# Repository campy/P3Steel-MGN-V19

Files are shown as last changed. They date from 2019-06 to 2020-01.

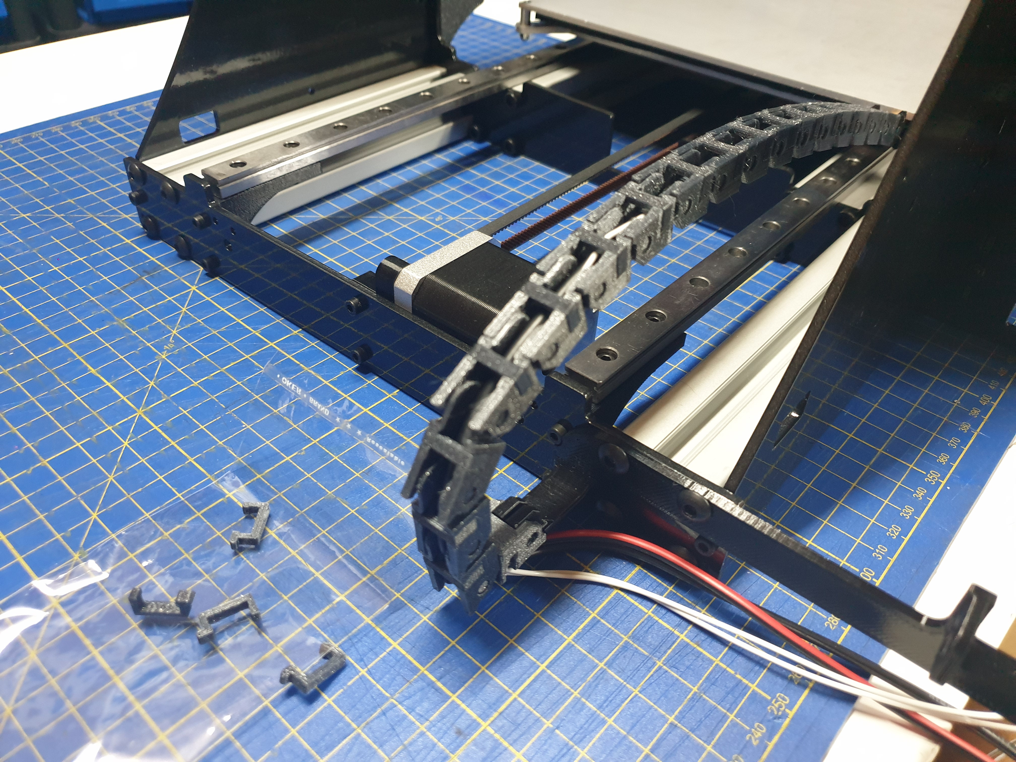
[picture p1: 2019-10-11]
P3Steel MGN Titan/Fotos ensamble/20191008_002519.jpg

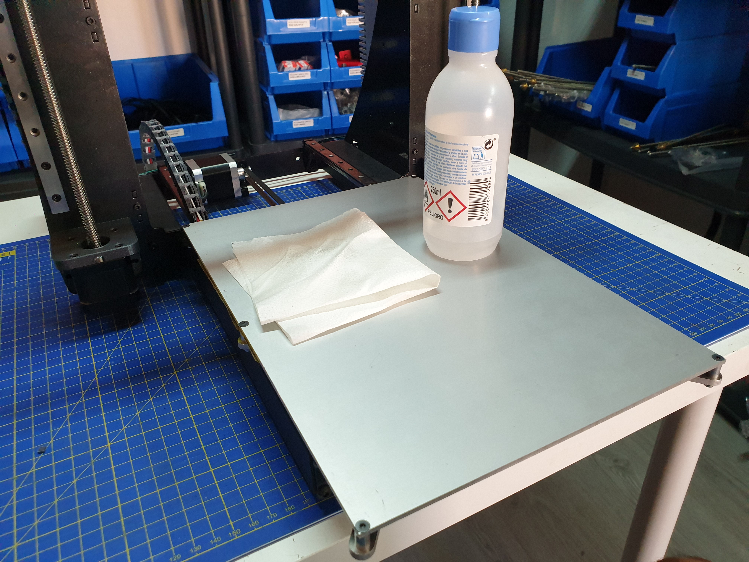
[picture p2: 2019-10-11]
P3Steel MGN Titan/Fotos ensamble/20191009_180815.jpg

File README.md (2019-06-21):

# P3Steel MGN 2019

## Licencia
Proyecto Open-Source con licencia CC BY-NC (No comercial)

Usted puede Compartir — copiar y redistribuir el material en cualquier medio o formato

Usted puede Adaptar — remezclar, transformar y construir a partir del material

NoComercial — Usted no puede hacer uso del material con propósitos comerciales

Atribución — Usted debe dar crédito de manera adecuada, brindar un enlace a la licencia, e indicar si se han realizado cambios. Puede hacerlo en cualquier forma razonable, pero no de forma tal que sugiera que usted o su uso tienen el apoyo de la licenciante.




##  Introducción
Diseñada desde cero por [3DCampy](https://blog.3despana.com/sobre-mi/) y con un año de desarrollo tengo el gusto de presentaros mi proyecto de P3steel

La evolución logica de nuestra querida P3steel, he cuidado hasta el ultimo detalle para que todo encaje a la perfección y la estetica sea lo mas limpia posible

En la wiki podrás ver todos los cambios y mejoras que se van implementando

La nueva P3steel 2019 está diseñada para los usuarios mas exigentes, el movimiento de todos los ejes es por guías lineales, lo que aporta una rigidez estructural y precisión extraordinaria.

Despues del desarrollo y muchas horas de pruebas la P3steel MGN V19 es una plataforma mas que testada y probada, que ademas vamos mejorando día a día con pequeñas mejoras.

Por poco dinero tendrás a tú disposición una impresora de escritorio profesional, robusta y duradera.

## Compatibilidades
- Compatible con extrusor Titan Aero
- Compatible con extrusor Bondtech + E3D V6
- Compatible con electronica MKS Gen L -Marlin 1.1.8-
- Compatible con electronica SKR 1.3 -Marlin 2.0-
- Compatible con electronica Duet 3D
- Compatible con pantalla MKS Mini 12864
- Compatible con pantalla Mini12864 RGB

## Información de cambios y mejoras
[Ir a Wiki](https://wiki.3despana.com/index.php?title=P3Steel_MGN_2019)

## Donde comprar los materiales o impresora completa
[3DEspana.com](https://3despana.com)

## Videos

[Youtube] (https://youtu.be/ORBLZrMCv2k)

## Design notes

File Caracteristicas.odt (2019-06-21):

P3STEEL MGN 2019

Características:

Chasis:

- Estructura de acero de 3mm reforzada con cuatro perfiles de 30x30mm
- Recubrimiento anti-corrosión al polvo en negro metalizado
- Tornilleria DIN 912 pavonada en negro mate

Dimensiones de impresión útiles:

- Eje X – 214mm
- Eje Y – 314mm
- Eje Z – 210mm / 200 (BMG)

Cimematica:

- Cinemática cartesiana mediante guiás lineales de 12mm en todos los ejes
- Patines de re-circulación de bolas en todos los ejes
- Poleas de 16 dientes en XY para mejorar la precisión
- Poleas sincronizadoras dentadas en XY
- Correa de nylon reforzada anti-fricción en XY
- Motores nema 17 con husillo integrado en el eje en el eje Z
- Tuercas Z Pom con muelle y sistema anti-backlash

Motores:

- Motor nema 17 de 1,7ah en eje X
- Motor nema 17 de 2,5ah en eje Y
- Motor nema 17 22mm de bajo peso en el extrusor

Electrónica:

- Placa controladora SKR V1,3 de 32bits
- Cableado de la placa crimpado en conectores JST
- Driver TCM2130 SPI silenciosos controlados por firmware
- Sistema de homing sin finales de carrera
- Driver TMC2208 UART con protector de diodos en el extrusor
- Firmware Marlin 2,0 implementado
- Pantalla RBG 12864 con lector de tarjeta
- Fuente de alimentación 24V 20Ah
- Termistores de temperatura 104-Gt2 de alta precisión en la base y en el nozzle
- Cartucho calefactable de 50w
- Sistema autonivel de 16 puntos mediante un sensor inductivo

Extrusión:

- Boquilla de 0,4mm con acabado electro-pulido
- Filamento de 1,75mm
- Sensor de final de filamento con asistente de cambio de filamento
- Impresión multi-color manual
- Barrel de titanio TC4 anti-goteo
- Funda de silicona protectora en el bloque calefactor
- Extrusión directa guiada para evitar atascos y compatible con filamento flexible
- Extrusor con desmultiplicacion 1/3 de par
- Dos tipos de extrusores a elegir: Titan Aero / BMG

Ventiladores:

- Ventilador de la fuente sustituido por un ventilador de rodamiento dual (Silencioso)
- Ventilador de capa blower de rodamiento dual de 5000rpm
- Ventilador de extrusión de rodamiento dual
- Filtro anti-polvo (Solo en titan)
- Ventilador de electrónica con rodamiento dual silencioso

Base de impresión:

- Superficie de impresión magnética y flexible
- Lamina de impresión de alta adherencia para evitar warping
- Superficies de impresión intercambiables para producción de piezas
- Aislamiento inferior de la superficie para evitar variaciones de temperatura
- Base caliente de aluminio calefactada hasta 120º

Conectividad y Alimentación:

- Conector C14 europeo con interruptor
- Carga de archivos mediante USB o SD
- *Opcional: servidor wifi de gestión de impresiones (Octoprint)

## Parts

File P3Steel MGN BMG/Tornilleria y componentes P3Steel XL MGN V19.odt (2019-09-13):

***********************************

****** GUÍAS LINEALES *******

***********************************

EJE Y

- 2 Guías de 450 mm MGN12C + 4 patines MGN12C

EJE Z y X

- 3 Guías de 500 mm MGN12C + 3 patines MGN12C

***********************************

****** PERFILES 30X30 *******

***********************************

2 Perfiles 30x30 --- 285mm (Zona delantera)

2 Perfiles 30x30 --- 166mm (zona trasera)

***********************************

****** ESTRUCTURA ***********

***********************************

Estructura General

- 12 Tornillos M3x12 (6 por lado)
- 12 tuercas M3 incrustadas en la estructura (6 por cada lado)

Unión de Perfiles con soportes de Metal

- 32 tornillos M5x12

***********************************

****** EJE Y ********************

***********************************

Sujeción Y a las guías 30x30 | (EJ: Pieza 12 a Pieza 22)

- 14 Tornillos M3x10 (7 por guia)
- 14 Tuercas T-Nut (7 por guia)

Sujeción piezas impresa al soporte metal (guías Y) (EJ: Pieza 13 a Pieza 23)

- 4 tornillos M3x10 (2 para cada pieza)
- 4 tuercas T-Nut de perfil 2020 (2 para cada pieza)

Soporte Motor Y a Estructura (EJ: Pieza 16 a Pieza 25)

- 2 Tornillos M3x12
- 2 tuercas m3

Final de carrera Y (EJ: Pieza 15 a Pieza 27)

- 2 Tornillos M3x10
- 2 tuercas M3

Y idler a estructura (soporte Rodamiento Y)

- 3 Tornillos M3x10
- 3 tuercas M3

Polea 3mm a pieza impresa

- 1 Tornillo M3x25
- 1 Tuerca autoblocante M3

Y holder a bandeja (Soporte correa Y)

- 2 Tornillos M3x12
- 2 Tuerca autoblocante M3

Sujeción patines a bandeja

- Cantidad 12 Tornillos M3x8

Motor Y a Soporte

- Cantidad 2 Tornillos M3x10

Soporte cadeneta a base

- Cantidad 1 Tornillo M3x12

Sujeción X a las guías

- 12 Tornillos M3x16

Cama a base aluminio Y

- 5 Tornillos M3x20 Avellanados
- 5 Tuercas autoblocante

***********************************

****** EJE X ********************

***********************************

X-motor - X-idler a Guia Z

- 8 Tornillos M3x8

X-Carriage a Guia de X

- 4 Tornillos M3x8

Sujeccion Guia X a Pieza Impresa X-Motor y X-idler

- 2 Tornillos M3x18 (1 para X-motor y 1 para X-idler)
- 1 Tornillo M3x16 para X-motor (El que coincide con la guia de Z)
- 1 Tornillo M3x14 para X-idler (El que coincide con la guia de Z)
- 4 Tuercas M3

Polea X a X-Idler

- 1 Tornillo M5x30
- 1 Tuerca Autoblocantes

Motor X a Pieza Impresa

- 4 Tornillos M3x10
- 4 Arandelas

***********************************

****** EJE Z ********************

***********************************

Sujeción Guías de Z a estructura de metal

- 12 Tornillos M3 (7 para cada Z)
- 12 Tuercas Autoblocantes (7 para cada Z)

Soporte impreso de motor Z a estructura metal

- 3 Tornillos M3X12
- 6 tuercas M3

Tuerca Husillos de X en pieza impresa

- 6 tornillos M3x12 (3 para cada lado)
- 6 Tuerca autoblocantes (3 para cada lado)

Motores Z a Pieza Impresa Z

- 4 Tornillos M3x8 por cada motor

***********************************

****** CORREAS ***************

***********************************

Correa X 960mm

Correa Y 910mm

***********************************

****** CABLEADO *************

***********************************

600mm Cable de fuente a placa alimentacion

900mm Cable cama a electronica

***********************************

****** ELECTRÓNICA *********

***********************************

Soporte Fuente a Marco + Soporte tapa fuente

4 Tornillos M4x6

Conector C14

2 Tornillos M3x8 Avellanado

2 Tuercas M3

Soporte placa a Marco (electronica + raspy)

4 Tornillos M3x10 Avellanados

Raspy y skr a soporte electrónica

8 Tornillos M3x6

8 insertos (4 por cada placa)

Soporte endstop Y

2 Tornillos M3x10

Soporte bobina filamento

1 Tornillo M3x12 (no entra, aun estando la tuerca incrustada)

1 Tornillo M3x18

1 Tuerca M3

Sensor de filamento a soporte impreso

2 Tornillos M3x18

2 Tuercas M3

Sensor de Filamento a marco de metal superior

1 Tornillo M3x18

Ventilador electrónica a tapa 3x18 avellanado

2 Tornillos M3x18

2 Tuercas M3

LCD RBG

2 Tornillo M3x6

2 Tornillo M3x16

4 insertos

Tapa electrónica

1 Tornillo M3x50

1 Tuerca M3

***********************************

****** INSERTOS **************

***********************************

20 Insertos M3

1 Inserto M6

***********************************

****** TITAN *********

***********************************

1- Anclaje titan no aero a motor 3x10

3- Anclaje aero a motor 3X35 + 4 Arandelas + 1 3x30 corto (Todos con arandela)

2- Ventilador aero 3x16 Avellanados para filtro

2- Ventilador Blower a soporte vent capa 3x20

2- Soporte cadeneta a Vent capa 3x8

Sensor inductivo 24mm desde salida del cable a X carriage

Tubo PTFE Titan 41.60mm (Barrel 4.1)

Tubo PTFE Titan 23.50mm (Barrel TC4)

***********************************

****** BMG *********************

***********************************

Anclaje soporte a guia

- 4 Tornillos M3x8

Anclaje bmg a soporte

- 3 Tornillos M3x36.2 (especiales)

Soporte fan layer a carro central

- 4 Tornillos M3x12
- 4 arandelas

Soporte cadeneta a x carro

- 4 Tornillos M3x6
- 2 Insertos En carro central

Ventilador blower a soporte impreso

- 2 Tornillos M3x20
- Usadas tuercas M3 acero. No hay tuerca de Nylon en el pack

***********************************

****** CADENETAS ************

***********************************

EJE Y (cama)

- 20x Eslabon 5

EJE Z

- 23x Eslabones
- 21 tapas R
- 2 tapas finas

CASO BMG (EJE X)

- 23 Eslabones + Eslabon Bloqueado
- 21 tapas L
- 1 tapa fina

CASO TITAN (EJE X)

- 18 Eslabones 15 (Eje X)
- 16 Tapas L
- 2 Tapa fina

TORNILLOS CADENETAS
Xmotor a Soporte de Cadeneta

- 4 Tornillos M3X6
- 4 insertos

X-Carriage a Soporte de Cadeneta

- 2 tornillos M3x8

***********************************

****** CABLES

***********************************

Estos son los alargamientos necesarios de cables:

EJE X a Electrónica

- 1 metro extra cable 2 nucleos 24 awg calentador Hotend.
- 1 metro extra cable 2 nucleos 28 awg Termistor Hotend.
- 1 metro extra cable 3 nucleos 28 awg inductor.
- 1 metro extra cable 2 nucleos 28 awg para Ventilador capa
- 1 metro extra cable 2 nucleos 28 awg para ventilador Extrusor
- 1,5 metro extra cable para Final de carrera de X

Fuente a Electrónica:

- 1,4 metros cable 2.5mm de Fuente a Electrónica (Cable Positivo, Negativo y Tierra)
- 1,4 metros cable 4mm de Fuente a Mofset (cable Positivo y Negativo)

Cama a Electrónica:

- 1 Metro cable 4mm de Mofset a cama (cable Positivo y Negativo)
- 1 Metro cable 28 AWG Termistor a Electrónica (Positivo y Negativo)

Enchufe CP12:

- 3 cables de 4 cm 2.5mm para puentes
- 3 cables de 8 cm de 2.5mm hasta fuente de alimentacion

***********************************

****** VREF DRIVERS ********

***********************************

TMC 2208

- X - 750mv
- Y - 800mv (0.9ยบ - 1300mv)
- Z - 800mv
- E - 750mv

TMC 2209

- X - ???mv
- Y - ???mv
- Z - ???mv
- E - ???mv

TMC 2130

- X - ???mv
- Y - ???mv
- Z - ???mv
- E - ???mv

***********************************

****** SENSOR INDUCTIVO **

***********************************

5V - MARRON

GND - AZUL

1.25 - NEGRO

***********************************

****** SENSOR FILAMENTO**

***********************************

Pin 1.28 (X+)

Pin GND

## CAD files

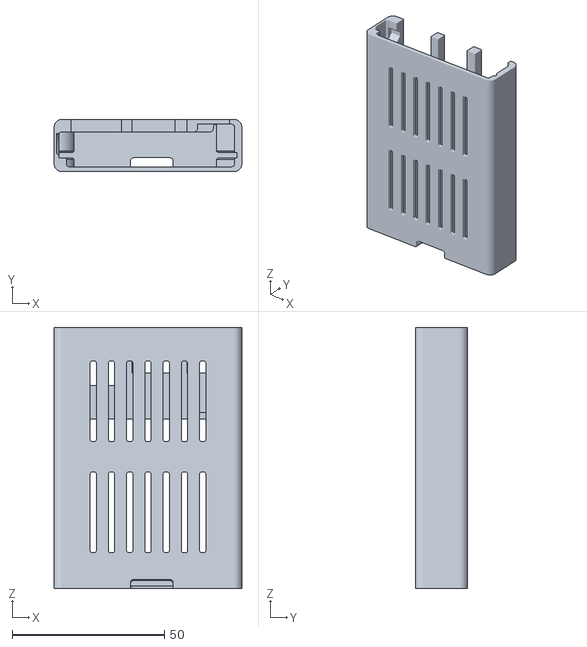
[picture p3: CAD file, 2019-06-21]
P3Steel MGN BMG/Piezas impresas/Raspberry box/Raspberry_Pi_B+_Sleeve_v2-1_MAIN.STL
61.7 x 17.2 x 85.8

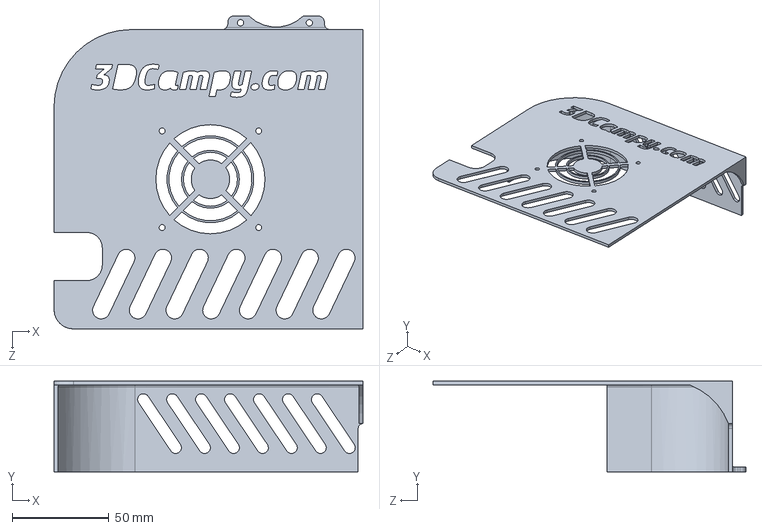
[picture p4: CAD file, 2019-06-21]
P3Steel MGN BMG/Piezas impresas/Soportes electronicas/Tapa Electronica antigua/Tapa Total.SLDPRT
160.0 x 47.0 x 162.0 mm

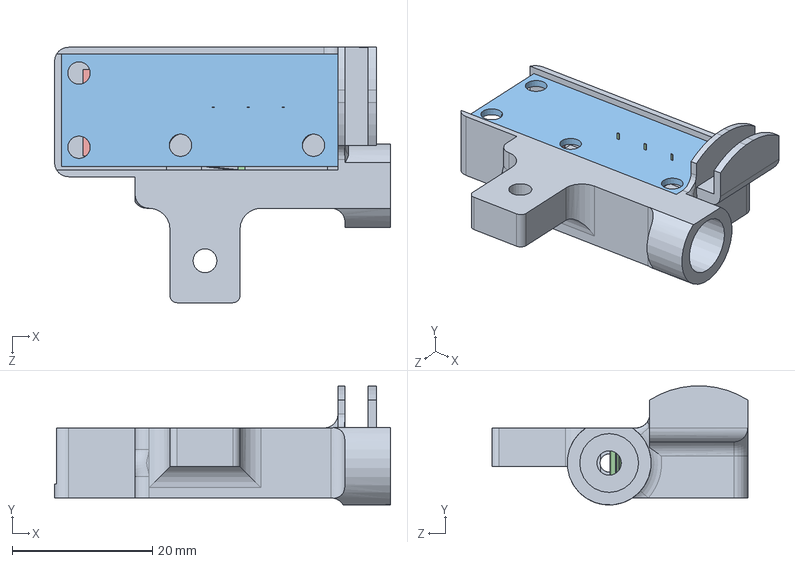
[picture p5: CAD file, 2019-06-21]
P3Steel MGN BMG/Source/F-Sensor/Ensamblaje F-Sensor.SLDASM
48.0 x 17.0 x 36.5 mm
Soporte F-Sensor
Konstruktion24
PCB^Endstop
Microswitch_1A_125vAC(seul)
JST 4Pin

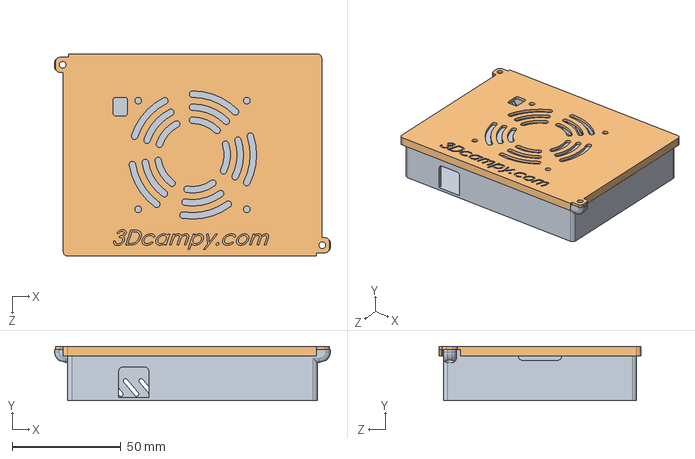
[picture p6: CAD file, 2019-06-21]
P3Steel MGN Titan/Piezas impresas/Soportes electronicas/Caja MKS SKR/EnsamblajeCajaMKS.SLDASM
127.0 x 25.0 x 93.0 mm
CajaMKSGen
TapaMKSGen

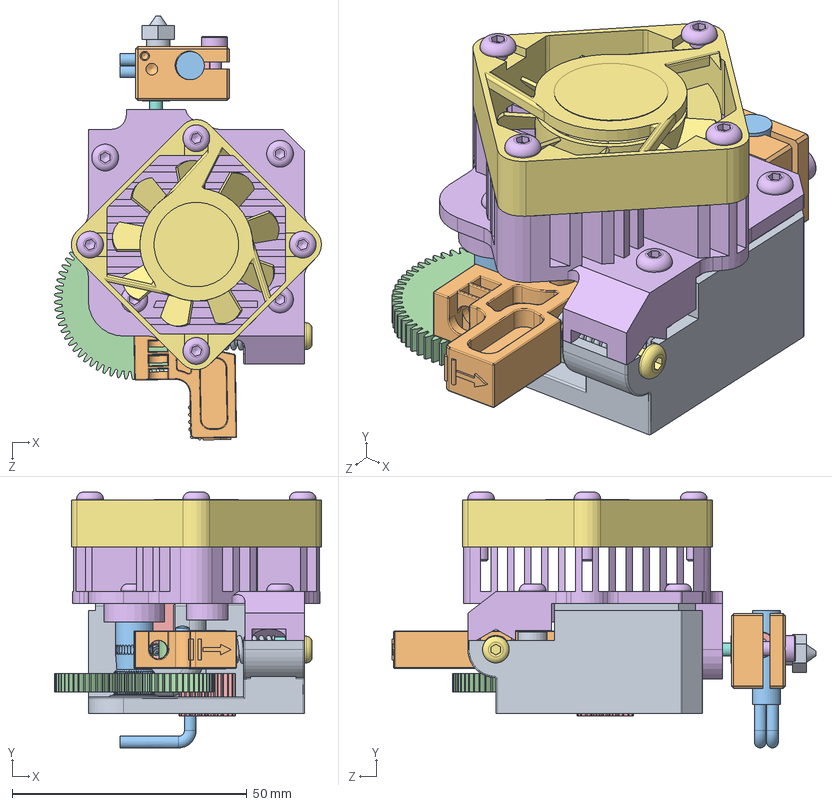
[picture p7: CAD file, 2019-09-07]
P3Steel MGN Titan/Source/Titan Aero/Titan Aero P3steel/e3d titan areo 1.751.SLDASM
56.8 x 54.4 x 90.2 mm
Base
9x5x3mm bearing x 2
hobbed wheel
filament gear
motor gear
cover
m3x8
M3 nut
idler spring
tensioner
idler bearing pin
idler bearing
guide tube
ISO 7380 - M3 x 28 v1 x 8
Fan 40 X 40 X 10 v4
E3D v6 HotEnd - Heatbreak
E3D v6 HotEnd - Nozzle
E3D v6 HotEnd - Heat Block
Ceramic Cartridge Heater
Thermistor
HEXAGON SOCKET HEAD CAP SCREWS_SCB3-4
HEXAGON SOCKET HEAD CAP SCREWS_SCB3-10
Flat Washers_PWF3

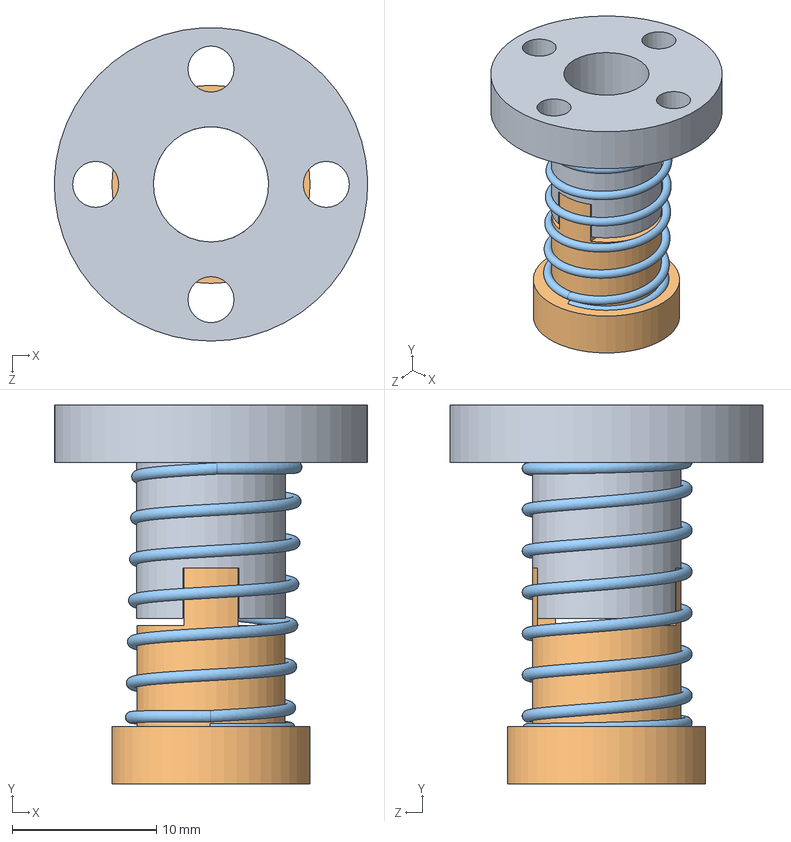
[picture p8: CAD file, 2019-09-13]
P3Steel MGN BMG/Ensamblaje-Xidler.SLDASM
21.7 x 26.3 x 21.7 mm
nakretka tr08
napinacz nakretki tr8
sprezyna nakretka tr 8

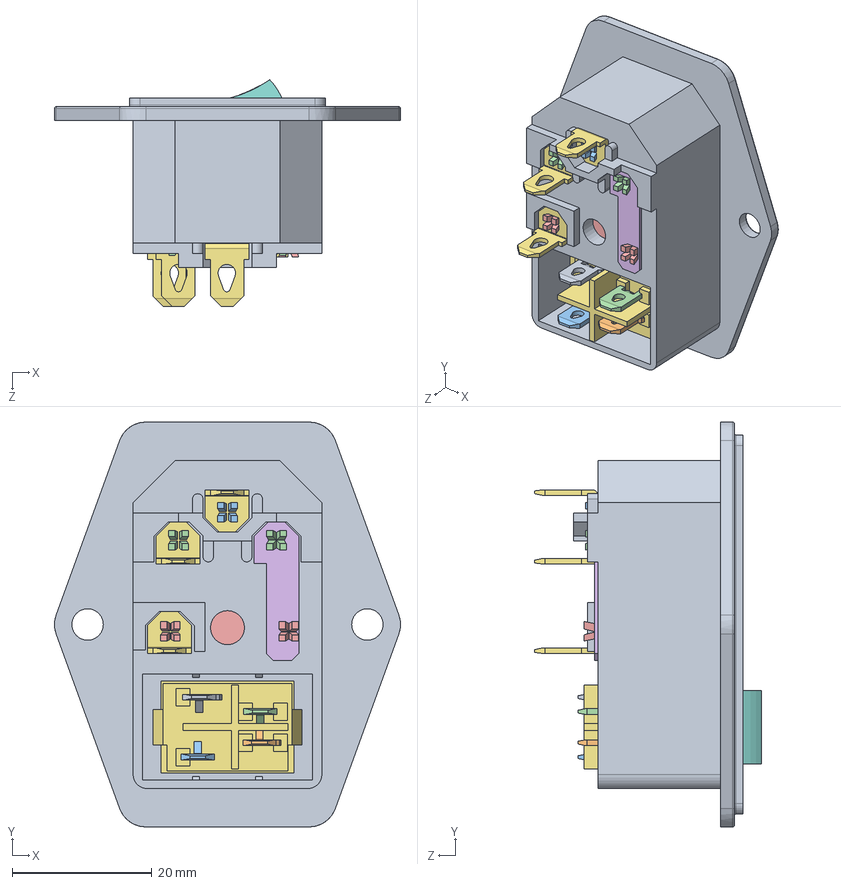
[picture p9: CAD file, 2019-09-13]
P3Steel MGN BMG/Source/Conector C14/IEC320-C14.SLDASM
49.5 x 57.9 x 32.4 mm
ilpm_case
fuse_clip_set
blade_15
blade_12 x 2
fuse-holder
fuse
switch_base
rocker
sm_tab_type1a
sm_tab_type1b
sm_tab_type2a
sm_tab_type2b
spot x 2
stamped_cond
correct_big_tab x 3

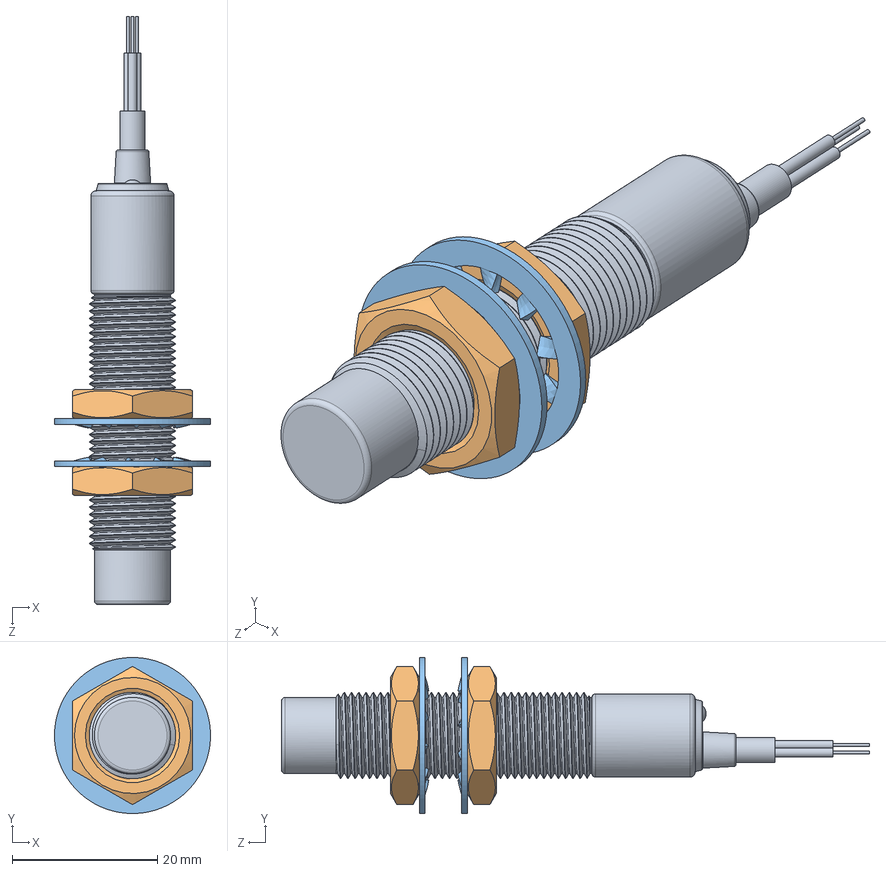
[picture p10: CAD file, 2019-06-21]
P3Steel MGN BMG/Source/Inductive Sensor/LJ12A3-4-Z.SLDASM
21.5 x 21.5 x 81.0 mm
LJ12A3-4-Z
Гайка М12 x 2
Шайба x 2

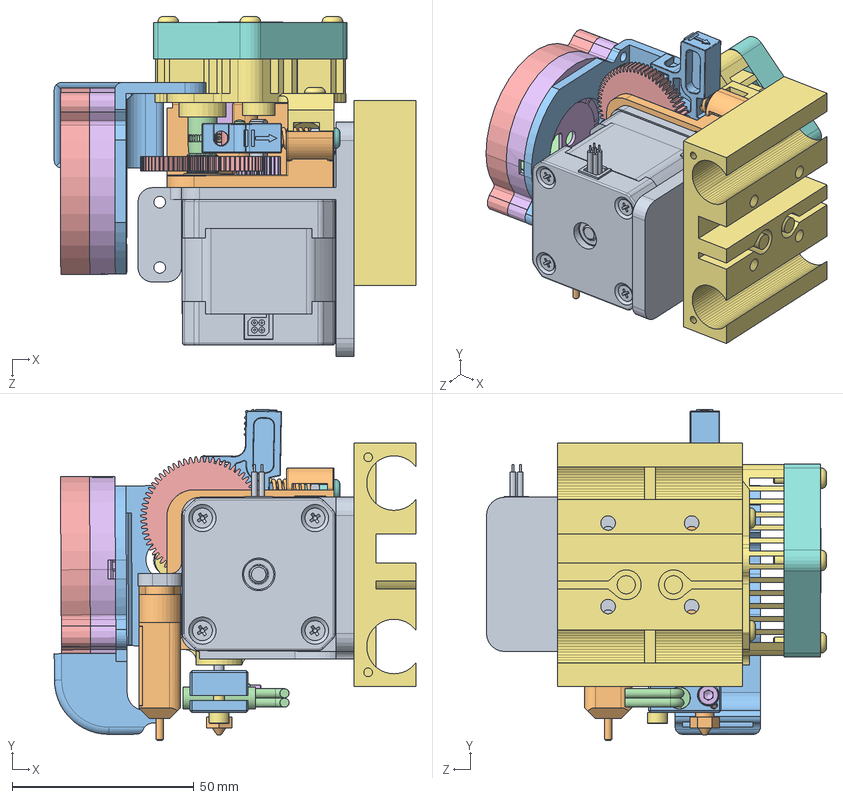
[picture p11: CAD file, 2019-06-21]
P3Steel MGN BMG/Source/Titan Aero/Titan Aero P3steel/soportetitan.SLDASM
99.6 x 91.2 x 93.6 mm
soportetitan
Base
9x5x3mm bearing x 2
hobbed wheel
filament gear
motor gear
cover
m3x8
M3 nut
idler spring
tensioner
idler bearing pin
idler bearing
guide tube
ISO 7380 - M3 x 28 v1 x 8
Fan 40 X 40 X 10 v4
E3D v6 HotEnd - Heatbreak
E3D v6 HotEnd - Nozzle
E3D v6 HotEnd - Heat Block
Ceramic Cartridge Heater
Thermistor
HEXAGON SOCKET HEAD CAP SCREWS_SCB3-4
HEXAGON SOCKET HEAD CAP SCREWS_SCB3-10
Flat Washers_PWF3
17HM15-0904S
BLTouch
tobera5015s
turbine
top
bottom
xcarriage

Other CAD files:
P3Steel MGN BMG/Piezas impresas/Soportes electronicas/Placas/Duet Wifi/2X5Pin case v6_1.sldasm
P3Steel MGN BMG/Source/Endstop/Component2.sldasm
P3Steel MGN Titan/Piezas impresas/Soportes electronicas/Placas/Duet Wifi/2X25Pin case v7.sldasm
P3Steel MGN Titan/Source/Endstop/Component3.sldasm
P3Steel MGN BMG/Source/F-Sensor/PCB.sldasm
P3Steel MGN Titan/Ensamblaje-Xidler.SLDASM
P3Steel MGN BMG/Bandeja 300.SLDPRT
P3Steel MGN BMG/Ensamblaje-Xmotor.SLDASM
P3Steel MGN BMG/Escuadra Central.SLDPRT
P3Steel MGN BMG/Escuadra Superior.SLDPRT
P3Steel MGN BMG/Extrusor/X-CarriageV2 BMG.SLDPRT
P3Steel MGN BMG/Extrusor/X-CarriageV2 BMG.STL
P3Steel MGN BMG/Frente.SLDPRT
P3Steel MGN BMG/Marco central.SLDPRT
P3Steel MGN BMG/Piezas impresas/Alzador.SLDPRT
P3Steel MGN BMG/Piezas impresas/Alzador.STL
P3Steel MGN BMG/Piezas impresas/Cadenetas/Cadeneta 15/Cierre 15 Tapa L.SLDPRT
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

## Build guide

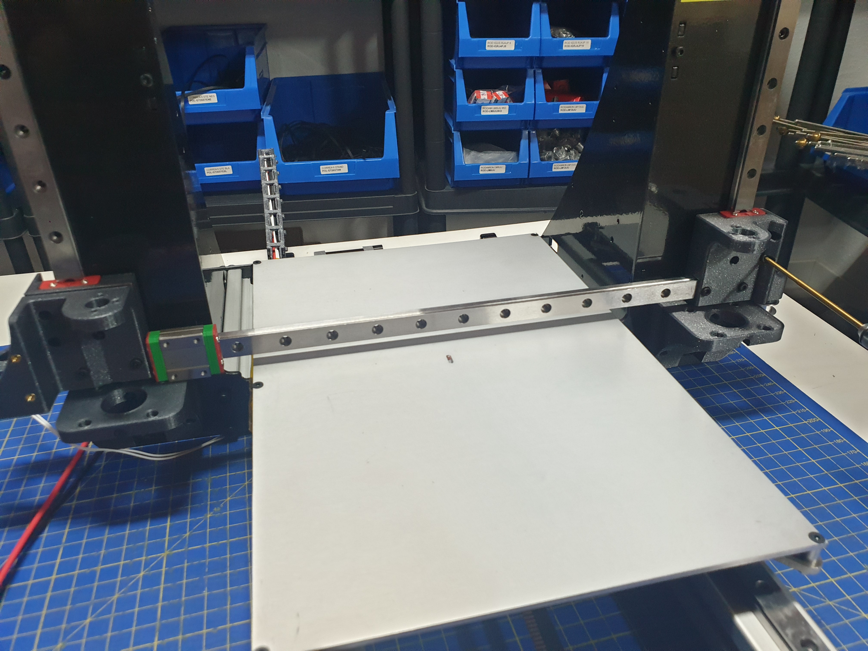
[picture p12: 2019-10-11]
P3Steel MGN Titan/Fotos ensamble/20191008_003525.jpg

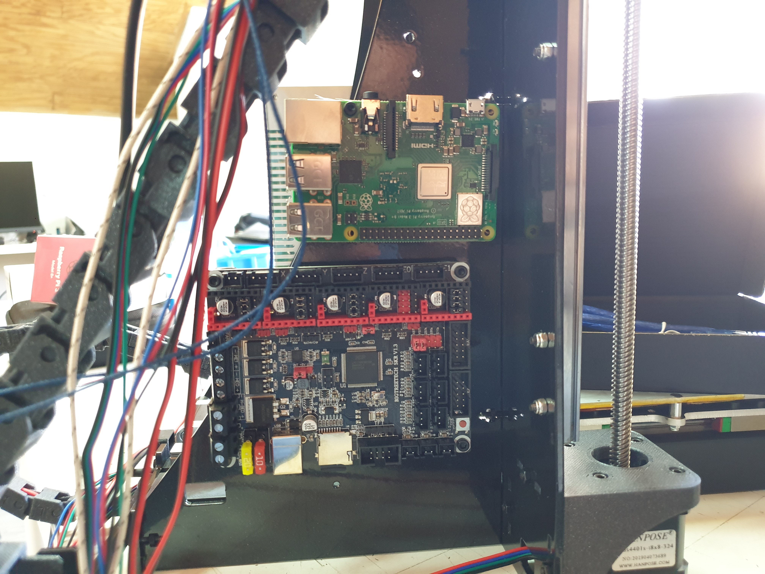
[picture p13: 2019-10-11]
P3Steel MGN Titan/Fotos ensamble/20191009_143709.jpg

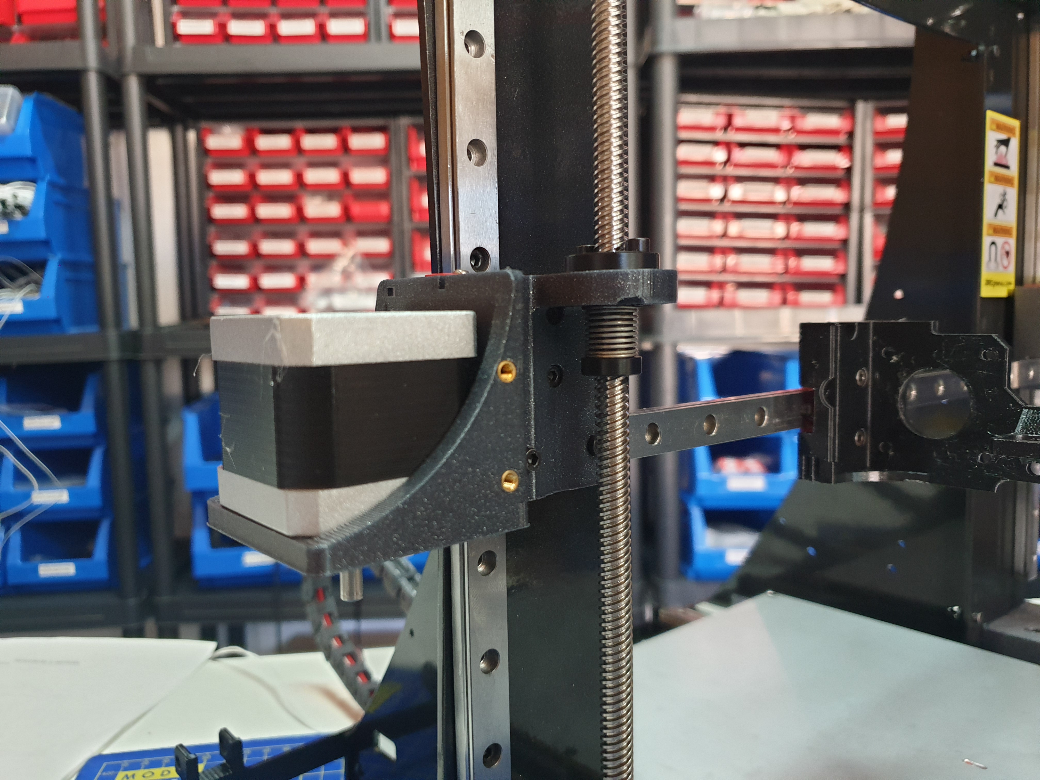
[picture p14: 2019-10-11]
P3Steel MGN Titan/Fotos ensamble/20191008_133851.jpg

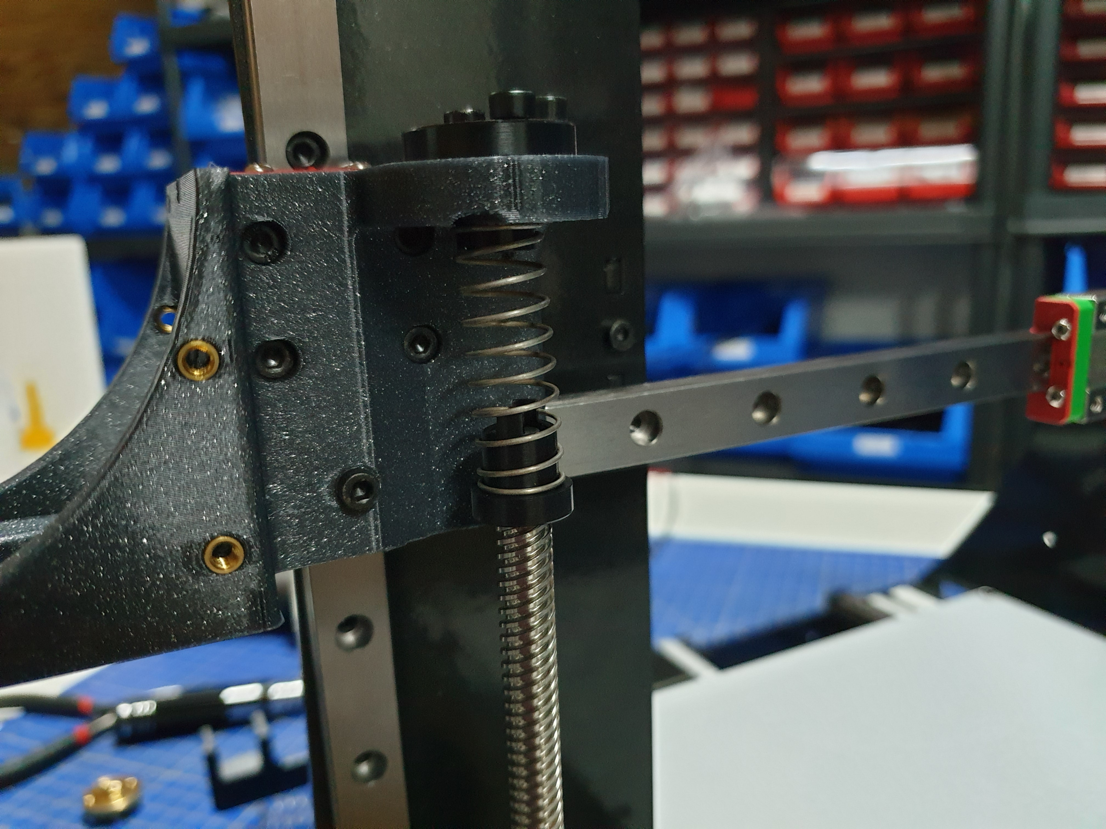
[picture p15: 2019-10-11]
P3Steel MGN Titan/Fotos ensamble/20191008_005819.jpg

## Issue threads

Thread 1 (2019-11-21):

Marlin 1.1.9

kikirikiki, 2019-11-21:
Hola,
he visto tu canal de youtube donde explicas la configuración de Marlin 1.1.9 entre otras cosas. Me ha encantado, muchas gracias.

He ido siguiendo tus indicaciones y llego a un punto donde no puedo continuar. Al acabar la configuracion, tengo un problema y es que no me compila el programa. He tenido que cambiar algo que no se lo que es y la he liado. Igual tu me puedes echar una mano, porque la verdad que no se por donde tirar.
Este es el error:
#error "DISABLE_[XYZ] is not compatible with HOME_AFTER_DEACTIVATE or Z_SAFE_HOMING."

Muchas gracias!!
Un saludo!

Joseba1478, 2020-04-15:
Hola Buenos días.
Soy nuevo por aquí y quisiera hacerme una impresora 3D y la verdad que la esteel v19 me encanta y quisiera hacerme una.
Quisiera saber como poder bajarme los planos de láser DXF.
Muchas gracias x todo.
Saludos.

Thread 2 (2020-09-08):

Motors not working in ramp 1.6 marlin 1.1.x

ammarfarsi, 2020-09-08:
hello.
I use marlin 1.1.9 on ramps 1.6 but the problem the motors not working. I check the connection but it is correct. also, I use Vref for a driver I try 0.3, 0.42, 0.52, 0.72 , 0.93V but still motors not working. I use pronterface to check the printer is connected but motors not move. i work with A4988 driver
[Marlin-bugfix-1.1.xmmm.zip](https://github.com/campy/P3Steel-MGN-V19/files/5189359/Marlin-bugfix-1.1.xmmm.zip)

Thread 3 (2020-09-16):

include errors detected, update include path

ammarfarsi, 2020-09-16:
i have this problem in vs code can any help me ?
#include errors detected. Please update your includePath. Squiggles are disabled for this translation unit (C:\Users\user\Desktop\Marlin-2.0.x\Marlin\src\MarlinCore.cpp).

abdallahelhady, 2023-06-25:
Is it solved with you?

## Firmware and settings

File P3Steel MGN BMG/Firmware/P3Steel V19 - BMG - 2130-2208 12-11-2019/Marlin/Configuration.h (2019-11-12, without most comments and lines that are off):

#pragma once
#define CONFIGURATION_H_VERSION 020000
#define STRING_CONFIG_H_AUTHOR "(none, default config)" // Who made the changes.
#define SHOW_BOOTSCREEN
#define SERIAL_PORT -1
#define BAUDRATE 115200
  #define MOTHERBOARD BOARD_BIGTREE_SKR_V1_3
#define CUSTOM_MACHINE_NAME "P3Steel V19"
#define EXTRUDERS 1
#define DEFAULT_NOMINAL_FILAMENT_DIA 1.75
#define TEMP_SENSOR_0 5
#define TEMP_SENSOR_1 0
#define TEMP_SENSOR_2 0
#define TEMP_SENSOR_3 0
#define TEMP_SENSOR_4 0
#define TEMP_SENSOR_5 0
#define TEMP_SENSOR_BED 11
#define TEMP_SENSOR_CHAMBER 0
#define DUMMY_THERMISTOR_998_VALUE 25
#define DUMMY_THERMISTOR_999_VALUE 100
#define MAX_REDUNDANT_TEMP_SENSOR_DIFF 10
#define TEMP_RESIDENCY_TIME     10  // (seconds) Time to wait for hotend to "settle" in M109
#define TEMP_WINDOW              1  // (°C) Temperature proximity for the "temperature reached" timer
#define TEMP_HYSTERESIS          3  // (°C) Temperature proximity considered "close enough" to the target
#define TEMP_BED_RESIDENCY_TIME 10  // (seconds) Time to wait for bed to "settle" in M190
#define TEMP_BED_WINDOW          1  // (°C) Temperature proximity for the "temperature reached" timer
#define TEMP_BED_HYSTERESIS      3  // (°C) Temperature proximity considered "close enough" to the target
#define HEATER_0_MINTEMP   5
#define HEATER_1_MINTEMP   5
#define HEATER_2_MINTEMP   5
#define HEATER_3_MINTEMP   5
#define HEATER_4_MINTEMP   5
#define HEATER_5_MINTEMP   5
#define BED_MINTEMP        5
#define HEATER_0_MAXTEMP 275
#define HEATER_1_MAXTEMP 275
#define HEATER_2_MAXTEMP 275
#define HEATER_3_MAXTEMP 275
#define HEATER_4_MAXTEMP 275
#define HEATER_5_MAXTEMP 275
#define BED_MAXTEMP      150
#define PIDTEMP
#define BANG_MAX 255     // Limits current to nozzle while in bang-bang mode; 255=full current
#define PID_MAX BANG_MAX // Limits current to nozzle while PID is active (see PID_FUNCTIONAL_RANGE below); 255=full current
#define PID_K1 0.95      // Smoothing factor within any PID loop
  #define PID_EDIT_MENU         // Add PID editing to the "Advanced Settings" menu. (~700 bytes of PROGMEM)
  #define PID_AUTOTUNE_MENU     // Add PID auto-tuning to the "Advanced Settings" menu. (~250 bytes of PROGMEM)
  #define PID_FUNCTIONAL_RANGE 10 // If the temperature difference between the target temperature and the actual temperature
  #define DEFAULT_Kp 11.0
  #define DEFAULT_Ki 0.62
  #define DEFAULT_Kd 48.67
#define PIDTEMPBED
#define MAX_BED_POWER 255 // limits duty cycle to bed; 255=full current
  #define DEFAULT_bedKp 794.49
  #define DEFAULT_bedKi 93.60
  #define DEFAULT_bedKd 1686.01
#define PREVENT_COLD_EXTRUSION
#define EXTRUDE_MINTEMP 170
#define PREVENT_LENGTHY_EXTRUDE
#define EXTRUDE_MAXLENGTH 200
#define THERMAL_PROTECTION_HOTENDS // Enable thermal protection for all extruders
#define THERMAL_PROTECTION_BED     // Enable thermal protection for the heated bed
#define THERMAL_PROTECTION_CHAMBER // Enable thermal protection for the heated chamber
#define USE_XMIN_PLUG
#define USE_YMIN_PLUG
#define USE_ZMIN_PLUG
#define ENDSTOPPULLUPS
#define X_MIN_ENDSTOP_INVERTING true // Set to true to invert the logic of the endstop.
#define Y_MIN_ENDSTOP_INVERTING true // Set to true to invert the logic of the endstop.
#define Z_MIN_ENDSTOP_INVERTING true // Set to true to invert the logic of the endstop.
#define X_MAX_ENDSTOP_INVERTING false // Set to true to invert the logic of the endstop.
#define Y_MAX_ENDSTOP_INVERTING false // Set to true to invert the logic of the endstop.
#define Z_MAX_ENDSTOP_INVERTING false // Set to true to invert the logic of the endstop.
#define Z_MIN_PROBE_ENDSTOP_INVERTING true // Set to true to invert the logic of the probe.
#define X_DRIVER_TYPE  TMC2130
#define Y_DRIVER_TYPE  TMC2130
#define Z_DRIVER_TYPE  TMC2130
#define E0_DRIVER_TYPE TMC2208
#define DEFAULT_AXIS_STEPS_PER_UNIT   { 100, 100, 400, 415 }
#define DEFAULT_MAX_FEEDRATE          { 100, 100, 8, 40 }
#define DEFAULT_MAX_ACCELERATION      { 1500, 1500, 500, 10000 }
#define DEFAULT_ACCELERATION          1500    // X, Y, Z and E acceleration for printing moves
#define DEFAULT_RETRACT_ACCELERATION  1500    // E acceleration for retracts
#define DEFAULT_TRAVEL_ACCELERATION   1500    // X, Y, Z acceleration for travel (non printing) moves
#define DEFAULT_EJERK    5.0  // May be used by Linear Advance
  #define JUNCTION_DEVIATION_MM 0.010 // (mm) Distance from real junction edge
#define Z_MIN_PROBE_USES_Z_MIN_ENDSTOP_PIN
#define Z_MIN_PROBE_PIN 25 // Pin 32 is the RAMPS default
#define FIX_MOUNTED_PROBE
#define NOZZLE_TO_PROBE_OFFSET { 0, -27, -3.0 }
#define MIN_PROBE_EDGE 10
#define XY_PROBE_SPEED 7000
#define Z_PROBE_SPEED_FAST HOMING_FEEDRATE_Z
#define Z_PROBE_SPEED_SLOW (Z_PROBE_SPEED_FAST / 2)
#define Z_CLEARANCE_DEPLOY_PROBE    5 // Z Clearance for Deploy/Stow
#define Z_CLEARANCE_BETWEEN_PROBES  5 // Z Clearance between probe points
#define Z_CLEARANCE_MULTI_PROBE     5 // Z Clearance between multiple probes
#define Z_AFTER_PROBING           5 // Z position after probing is done
#define Z_PROBE_LOW_POINT          -2 // Farthest distance below the trigger-point to go before stopping
#define Z_PROBE_OFFSET_RANGE_MIN -20
#define Z_PROBE_OFFSET_RANGE_MAX 20
#define X_ENABLE_ON 0
#define Y_ENABLE_ON 0
#define Z_ENABLE_ON 0
#define E_ENABLE_ON 0 // For all extruders
#define DISABLE_X false
#define DISABLE_Y false
#define DISABLE_Z false
#define DISABLE_E false             // For all extruders
#define DISABLE_INACTIVE_EXTRUDER   // Keep only the active extruder enabled
#define INVERT_X_DIR false
#define INVERT_Y_DIR true
#define INVERT_Z_DIR false
#define INVERT_E0_DIR false
#define INVERT_E1_DIR false
#define INVERT_E2_DIR false
#define INVERT_E3_DIR false
#define INVERT_E4_DIR false
#define INVERT_E5_DIR false
#define X_HOME_DIR -1
#define Y_HOME_DIR -1
#define Z_HOME_DIR -1
#define X_BED_SIZE 212
#define Y_BED_SIZE 310
#define X_MIN_POS 0
#define Y_MIN_POS 0
#define Z_MIN_POS 0
#define X_MAX_POS X_BED_SIZE
#define Y_MAX_POS Y_BED_SIZE
#define Z_MAX_POS 220
#define MIN_SOFTWARE_ENDSTOPS
  #define MIN_SOFTWARE_ENDSTOP_X
  #define MIN_SOFTWARE_ENDSTOP_Y
  #define MIN_SOFTWARE_ENDSTOP_Z
#define MAX_SOFTWARE_ENDSTOPS
  #define MAX_SOFTWARE_ENDSTOP_X
  #define MAX_SOFTWARE_ENDSTOP_Y
  #define MAX_SOFTWARE_ENDSTOP_Z
#define FILAMENT_RUNOUT_SENSOR
  #define NUM_RUNOUT_SENSORS   1     // Number of sensors, up to one per extruder. Define a FIL_RUNOUT#_PIN for each.
  #define FIL_RUNOUT_INVERTING true // Set to true to invert the logic of the sensor.
  #define FIL_RUNOUT_PULLUP          // Use internal pullup for filament runout pins.
  #define FILAMENT_RUNOUT_SCRIPT "M600"
#define AUTO_BED_LEVELING_BILINEAR
  #define ENABLE_LEVELING_FADE_HEIGHT
  #define SEGMENT_LEVELED_MOVES
  #define LEVELED_SEGMENT_LENGTH 5.0 // (mm) Length of all segments (except the last one)
  #define GRID_MAX_POINTS_X 4
  #define GRID_MAX_POINTS_Y GRID_MAX_POINTS_X
#define Z_SAFE_HOMING
  #define Z_SAFE_HOMING_X_POINT ((X_BED_SIZE) / 2)    // X point for Z homing when homing all axes (G28).
  #define Z_SAFE_HOMING_Y_POINT ((Y_BED_SIZE) / 2)    // Y point for Z homing when homing all axes (G28).
#define HOMING_FEEDRATE_XY (90*60)
#define HOMING_FEEDRATE_Z  (8*60)
#define VALIDATE_HOMING_ENDSTOPS
#define EEPROM_SETTINGS     // Persistent storage with M500 and M501
#define EEPROM_CHITCHAT       // Give feedback on EEPROM commands. Disable to save PROGMEM.
#define HOST_KEEPALIVE_FEATURE        // Disable this if your host doesn't like keepalive messages
#define DEFAULT_KEEPALIVE_INTERVAL 2  // Number of seconds between "busy" messages. Set with M113.
#define BUSY_WHILE_HEATING            // Some hosts require "busy" messages even during heating
#define PREHEAT_1_LABEL       "PLA"
#define PREHEAT_1_TEMP_HOTEND 205
#define PREHEAT_1_TEMP_BED     50
#define PREHEAT_1_FAN_SPEED     0 // Value from 0 to 255
#define PREHEAT_2_LABEL       "ABS"
#define PREHEAT_2_TEMP_HOTEND 220
#define PREHEAT_2_TEMP_BED     90
#define PREHEAT_2_FAN_SPEED     0 // Value from 0 to 255
#define NOZZLE_PARK_FEATURE
  #define NOZZLE_PARK_POINT { (X_MIN_POS + 10), (Y_MAX_POS - 10), 20 }
  #define NOZZLE_PARK_XY_FEEDRATE 100   // (mm/s) X and Y axes feedrate (also used for delta Z axis)
  #define NOZZLE_PARK_Z_FEEDRATE 5      // (mm/s) Z axis feedrate (not used for delta printers)
#define PRINTJOB_TIMER_AUTOSTART
#define PRINTCOUNTER
#define LCD_LANGUAGE es
#define DISPLAY_CHARSET_HD44780 JAPANESE
#define LCD_INFO_SCREEN_STYLE 0
#define SDSUPPORT
#define FYSETC_MINI_12864_1_2  // Type C/D/E/F. Simple RGB Backlight (always on)
#define SOFT_PWM_SCALE 0
#define SERVO_DELAY { 300 }

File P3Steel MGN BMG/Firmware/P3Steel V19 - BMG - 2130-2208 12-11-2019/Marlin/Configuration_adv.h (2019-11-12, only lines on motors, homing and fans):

#define E0_AUTO_FAN_PIN -1
#define E1_AUTO_FAN_PIN -1
#define E2_AUTO_FAN_PIN -1
#define E3_AUTO_FAN_PIN -1
#define E4_AUTO_FAN_PIN -1
#define E5_AUTO_FAN_PIN -1
#define CHAMBER_AUTO_FAN_PIN -1
#define X_HOME_BUMP_MM 0
#define Y_HOME_BUMP_MM 0
#define Z_HOME_BUMP_MM 2
#define HOMING_BUMP_DIVISOR { 2, 2, 4 }  // Re-Bump Speed Divisor (Divides the Homing Feedrate)
#define MICROSTEP_MODES { 16, 16, 16, 16, 16, 16 } // [1,2,4,8,16]
#define DIGIPOT_I2C_MOTOR_CURRENTS { 1.0, 1.0, 1.0, 1.0, 1.0, 1.0, 1.0, 1.0 }  //  AZTEEG_X3_PRO
#define LIN_ADVANCE
  #define LIN_ADVANCE_K 0.20    // Unit: mm compression per 1mm/s extruder speed
#define ADVANCED_PAUSE_FEATURE
  #define ADVANCED_PAUSE_PURGE_FEEDRATE        3  // (mm/s) Extrude feedrate (after loading). Should be slower than load feedrate.
  #define ADVANCED_PAUSE_PURGE_LENGTH         70  // (mm) Length to extrude after loading.
  #define ADVANCED_PAUSE_RESUME_PRIME          0  // (mm) Extra distance to prime nozzle after returning from park.
    #define X_CURRENT       750       // (mA) RMS current. Multiply by 1.414 for peak current.
    #define X_CURRENT_HOME  X_CURRENT  // (mA) RMS current for sensorless homing
    #define X_MICROSTEPS     16    // 0..256
    #define Y_CURRENT       925
    #define Y_CURRENT_HOME  Y_CURRENT
    #define Y_MICROSTEPS     16
    #define Z_CURRENT       800
    #define Z_CURRENT_HOME  Z_CURRENT
    #define Z_MICROSTEPS     16
    #define E0_CURRENT      720
    #define E0_MICROSTEPS    16
    #define CURRENT_STEP_DOWN     50  // [mA]
    #define REPORT_CURRENT_CHANGE
  #define X_HYBRID_THRESHOLD     100  // [mm/s]
  #define X2_HYBRID_THRESHOLD    100
  #define Y_HYBRID_THRESHOLD     100
  #define Y2_HYBRID_THRESHOLD    100
  #define Z_HYBRID_THRESHOLD       3
  #define Z2_HYBRID_THRESHOLD      3
  #define Z3_HYBRID_THRESHOLD      3
  #define E0_HYBRID_THRESHOLD     30
  #define E1_HYBRID_THRESHOLD     30
  #define E2_HYBRID_THRESHOLD     30
  #define E3_HYBRID_THRESHOLD     30
  #define E4_HYBRID_THRESHOLD     30
  #define E5_HYBRID_THRESHOLD     30
  #define SENSORLESS_HOMING // StallGuard capable drivers only
    #define X_STALL_SENSITIVITY  5
    #define X2_STALL_SENSITIVITY X_STALL_SENSITIVITY
    #define Y_STALL_SENSITIVITY  5

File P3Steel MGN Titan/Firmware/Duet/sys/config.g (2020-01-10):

; Configuration file for Duet WiFi (firmware version 1.21)
; executed by the firmware on start-up
;
; generated by RepRapFirmware Configuration Tool on Tue Oct 23 2018 00:51:50 GMT+0200 (hora de verano de Europa central)

; Logs
M929 P"eventlog.txt" S1         ; Guarda un log de lo que pasa con la placa eventlog.txt

; General preferences
G90                            ; Send absolute coordinates...
M83                            ; ...but relative extruder moves

; Network
M550 PP3Steel                  ; Set machine name
M552 S1                        ; Enable network
M586 P0 S1                     ; Enable HTTP
M586 P1 S0                     ; Disable FTP
M586 P2 S0                     ; Disable Telnet

; Drives
M569 P0 S0                     ; Drive 0 goes forwards
M569 P1 S0                     ; Drive 1 goes forwards
M569 P2 S0                     ; Drive 2 goes forwards
M569 P3 S0                     ; Drive 3 goes forwards
M350 X16 Y16 Z16 E16 I1        ; Configure microstepping with interpolation
M92 X100 Y200 Z400 E418        ; Set steps per mm
M566 X480 Y480 Z12 E500        ; Set maximum instantaneous speed changes (mm/min)
M203 X7000 Y7000 Z900 E3000    ; Set maximum speeds (mm/min)
M201 X1800 Y1800 Z500 E9000    ; Set accelerations (mm/s^2)
M906 X750 Y920 Z750 E710 I30   ; Set motor currents (mA) and motor idle factor in per cent
M84 S30                        ; Set idle timeout

; Axis Limits
M208 X0 Y0 Z0 S1               ; Set axis minima
M208 X214 Y314 Z220 S0         ; Set axis maxima

; Endstops
M574 X1 Y1 S0                  ; Set active low endstops

; Z-Probe
M574 Z1 S2                     ; Set endstops controlled by probe
M558 P5 I1 H5 F300 T6000          ; Set Z probe type to ultrasonic and the dive height + speeds
G31 P500 X3 Y-23 Z1.40        ; Set Z probe trigger value, offset and trigger height
M557 X10:210 Y10:290 S20       ; Define mesh grid

; Heaters
M307 H0 B0 S1.00               ; Disable bang-bang mode for the bed heater and set PWM limit
M305 P0 T100000 B3950 C0 R4700 ; Set thermistor + ADC parameters for heater 0
M143 H0 S120                   ; Set temperature limit for heater 0 to 120C
M305 P1 T100000 B4725 C7.06e-8 R4700 ; Set thermistor + ADC parameters for heater 1
M143 H1 S290                   ; Set temperature limit for heater 1 to 280C
M570 H1 P10 T50


; Fans
M106 P0 S0 I0 F500 H-1         ; Set fan 0 value, PWM signal inversion and frequency. Thermostatic control is turned off
M106 P1 S1 I0 F500 H1 T50      ; Set fan 1 value, PWM signal inversion and frequency. Thermostatic control is turned on
M106 P2 S1 I0 F500 H1 T45      ; Set fan 2 value, PWM signal inversion and frequency. Thermostatic control is turned on

; Tools
M563 P0 D0 H1                  ; Define tool 0
G10 P0 X0 Y0 Z0                ; Set tool 0 axis offsets
G10 P0 R0 S0                   ; Set initial tool 0 active and standby temperatures to 0C


;Filament sensor
M591 D0 P2 C3 S1

M911 S21.0 R23.0 P"M913 X0 Y0 G91 M83 G1 Z3 E-5 F1000"            ;Resume after power cut
M912 P0 S-17                   ;Cpu temp correction
M501                           ; Save eprom

; Automatic saving after power loss is not enabled

; Custom settings are not configured

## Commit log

2019-06-21 Publicacion
    Publicandooo
    [17HM15-0904S.SLDASM, 2 pole terminal block large v7.sldprt, 2 pole terminal block v7.sldprt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]
2019-06-27 General update
    General update
    [Delantera.SLDPRT, EndstopY.SLDPRT, EndstopY.STL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]
2019-07-04 General update
    New X-Idler
    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
    [Configuration.h, Configuration_adv.h, Ensamblaje-Xidler.SLDASM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]
2019-09-07 September update
    -Update X idler
    -Update fan layer support
    -Update X motor
    - Correct some things
    [2 pole terminal block large v7.sldprt, 2 pole terminal block v7.sldprt, 25 pin with case v2.sldasm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]
2019-09-13 Update
    New Update
    - New covers
    - Some modification
    - New parts
    - New rods
    [4x12.SLDPRT, Alzador.SLDPRT, BMG_Extruder v3.sldprt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]
2019-10-11 OCtober update
    -New firmware
    -New pictures of assambly
    -Some changes in printer parts
    [Centrador Guia-Perfil3030.STL, Configuration.h, Configuration_adv.h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]
2019-11-12 November update
    November update
    [Centrador Guia-Perfil3030.STL, Configuration.h, Configuration_adv.h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]
2020-01-10 2020 Update
    General update january 2020
    [Bandeja 300V2.DXF, Bandeja 300V2.SLDPRT, config.g]

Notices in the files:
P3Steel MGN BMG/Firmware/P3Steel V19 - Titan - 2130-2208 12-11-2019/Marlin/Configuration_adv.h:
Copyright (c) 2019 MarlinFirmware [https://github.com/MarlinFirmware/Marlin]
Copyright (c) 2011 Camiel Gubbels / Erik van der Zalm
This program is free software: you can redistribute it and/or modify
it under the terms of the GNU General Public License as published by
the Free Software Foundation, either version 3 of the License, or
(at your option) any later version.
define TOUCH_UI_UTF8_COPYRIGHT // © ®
